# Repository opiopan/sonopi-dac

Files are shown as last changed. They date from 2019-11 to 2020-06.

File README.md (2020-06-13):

Sonopi DAC
===


<p align="center">
board image
</p>

Sonopi DAC is a hat card for Raspberry Pi to add a audio line output capability.
This hat board is designed to adapt to both of formfactor, Raspbery pi model B+ and Raspberry pi Zero.<br>
[TI PCM5122](http://www.ti.com/product/PCM5122?keyMatch=PCM5122&tisearch=Search-EN-everything&usecase=part-number) is isntalled as DAC module, and Sonopi DAC design is compatible with [Hifiberry DAC+ Pro](https://www.hifiberry.com/shop/boards/hifiberry-dac-pro/) from Raspberry Pi point of view. It means that no special driver is necessary to use Sonopi DAC.

This hardware design is published under open source lincence. You can use and modify this design freely. There is also no limitation in commercial use.

## Project Status
Circuit schema design was done. Now I'm working on board art work.<br>
And I'm also considering which production is more feasible for some parts.

## How to setup
Due to enable drivers for Sonopi DAC in Linux ALSA system, add a following line in ```/boot/config.txt```. Then rebooot a Raspberry Pi.

```
dtoverlay=hifiberry-dacplus
```

## PCB Design
<p align="center">
PCB schema
</p>

<p align="center">
board image
</p>

<p align="center">
board image
</p>

<p align="center">
board image
</p>

## BOM List
Components               | Value / Product Number      | Remarks
-------------------------|-----------------------------|------------------------------
U1                       | PCM5122                     |
U2                       | MCP1703AT-3302E/CB          | 3.3V LDO
X1                       | 22.5792MHz Oscillator (3225)|
X2                       | 24.576MHz Oscillator (3225) |
R1, R2                   | 470Ω (1608)                 |
C1, C2                   | 1uF (1608)                  |
C3, C5, C7, C11          | 10uF/16V (3216)             |
C4, C6, C8, C12, C13, C14| 0.1uF/100V (1608)           |
C9, C10                  | 2.2uF/25V (2012)            |
C15, C16                 | 2.2nF/50V (1608)            |
J1                       | HLR-3201VXB-004HG           | RCA Jack (White)
J2                       | HLR-3201VXB-003HG           | RCA Jack (Red)

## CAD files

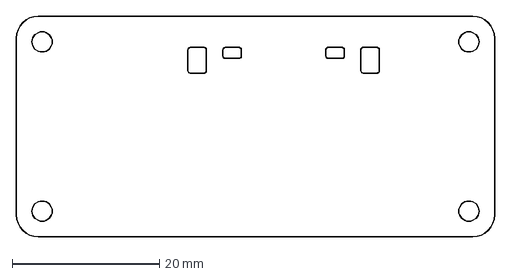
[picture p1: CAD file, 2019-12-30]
imagesrc/3dcg/outline.dxf
65.0 x 30.0 mm

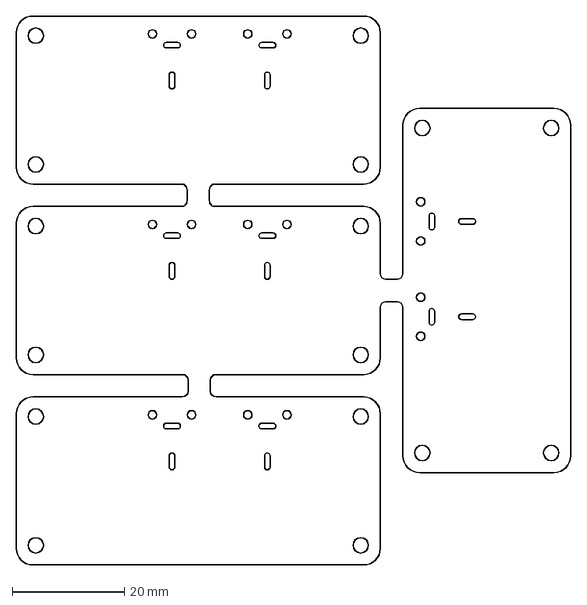
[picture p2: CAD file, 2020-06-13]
panelize/outline.dxf
99.0 x 98.0 mm

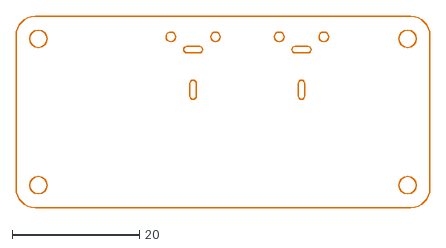
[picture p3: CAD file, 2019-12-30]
pcb/type2/sonopi-dac-type2.dxf
65.0 x 30.0

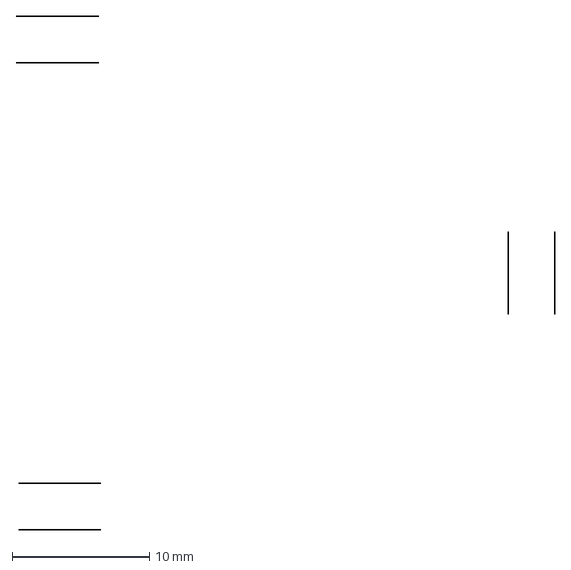
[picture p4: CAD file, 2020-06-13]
panelize/mousebites.dxf
39.2 x 37.4 mm

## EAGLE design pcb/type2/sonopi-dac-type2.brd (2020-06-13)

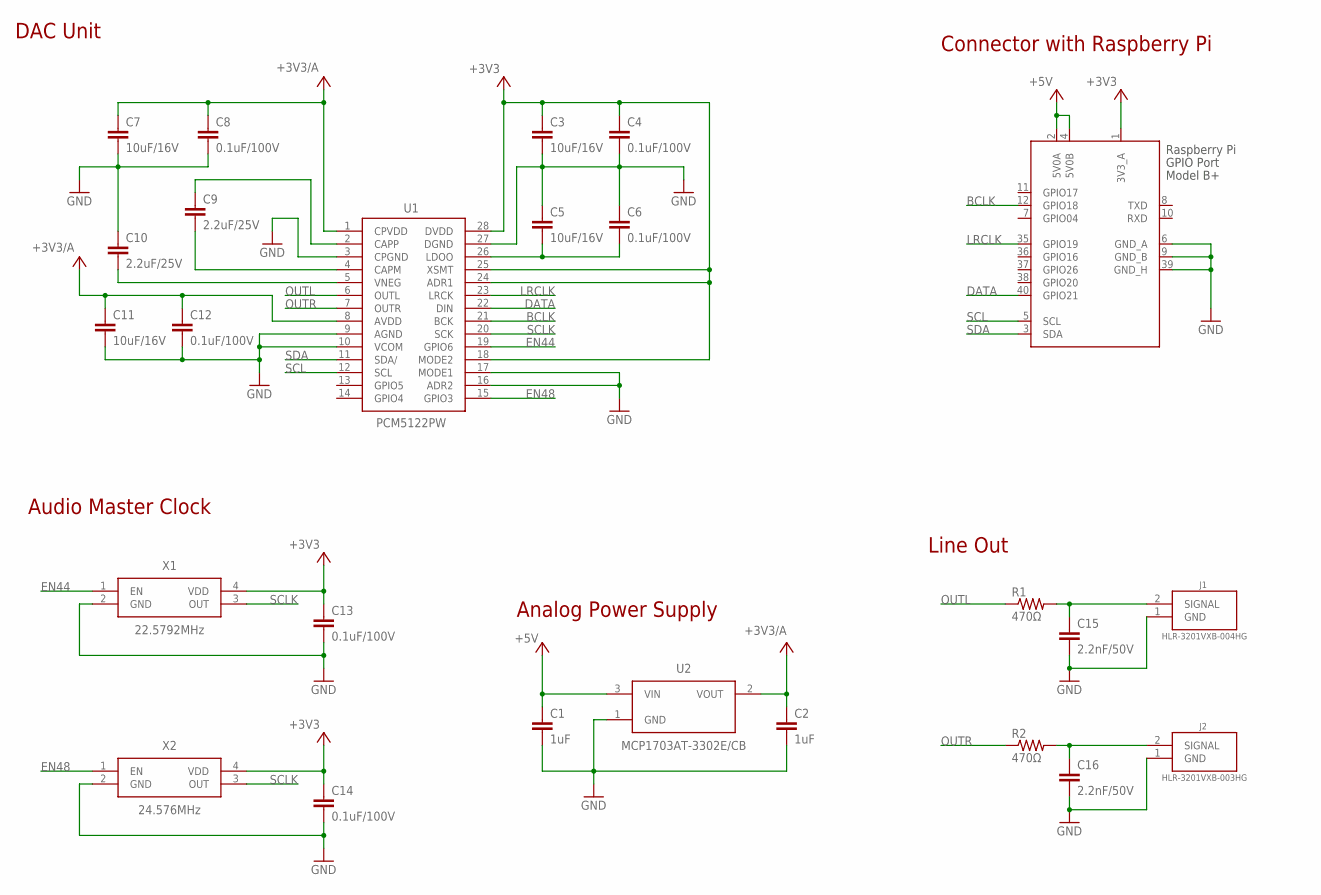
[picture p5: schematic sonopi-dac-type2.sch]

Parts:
C1, C2: 1uF; C0603
C3, C5, C7, C11: 10uF/16V; C3216
C4, C6, C8, C12, C13, C14: 0.1uF/100V; C0603
C9, C10: 2.2uF/25V; C0805
C15, C16: 2.2nF/50V; C0603
J1: HLR-3201VXB-004HG; HLR-3201VXB
J2: HLR-3201VXB-003HG; HLR-3201VXB
J3: RASPI_BOARD_B+#_ZERO; RASPI_BOARD_B+HAT_ZERO
R1, R2: 470Ω; R0603
U1: PCM5122PW; SOP65P640X120-28N
U2: MCP1703AT-3302E/CB; SOT23
X1: 22.5792MHz; 3225-SMD-HS
X2: 24.576MHz; 3225-SMD-HS

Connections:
+3V3: C3.1, C4.1, C13.1, C14.1, J3.1 (3V3_A), U1.18 (MODE2), U1.24 (ADR1), U1.25 (XSMT), U1.28 (DVDD), X1.4 (VDD), X2.4 (VDD)
+3V3/A: C2.1, C7.1, C8.1, C11.1, C12.1, U1.1 (CPVDD), U1.8 (AVDD), U2.2 (VOUT)
+5V: C1.1, J3.2 (5V0A), J3.4 (5V0B), U2.3 (VIN)
BCLK: J3.12 (GPIO18), U1.21 (BCK)
CAPM: C9.2, U1.4 (CAPM)
CAPP: C9.1, U1.2 (CAPP)
DATA: J3.40 (GPIO21), U1.22 (DIN)
EN44: U1.19 (GPIO6), X1.1 (EN)
EN48: U1.15 (GPIO3), X2.1 (EN)
GND: C1.2, C2.2, C3.2, C4.2, C5.1, C6.1, C7.2, C8.2, C10.1, C11.2, C12.2, C13.2, C14.2, C15.2, C16.2, J1.1 (GND), J2.1 (GND), J3.6 (GND_A), J3.9 (GND_B), J3.39 (GND_H), U1.3 (CPGND), U1.9 (AGND), U1.10 (VCOM), U1.16 (ADR2), U1.17 (MODE1), U1.27 (DGND), U2.1 (GND), X1.2 (GND), X2.2 (GND)
LCH: C15.1, J1.2 (SIGNAL), R1.2
LDOO: C5.2, C6.2, U1.26 (LDOO)
LRCLK: J3.35 (GPIO19), U1.23 (LRCK)
OUTL: R1.1, U1.6 (OUTL)
OUTR: R2.1, U1.7 (OUTR)
RCH: C16.1, J2.2 (SIGNAL), R2.2
SCL: J3.5 (SCL), U1.12 (SCL)
SCLK: U1.20 (SCK), X1.3 (OUT), X2.3 (OUT)
SDA: J3.3 (SDA), U1.11 (SDA/)
VNEG: C10.2, U1.5 (VNEG)

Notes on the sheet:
Analog Power Supply
Connector with Raspberry Pi
DAC Unit
Audio Master Clock
Line Out

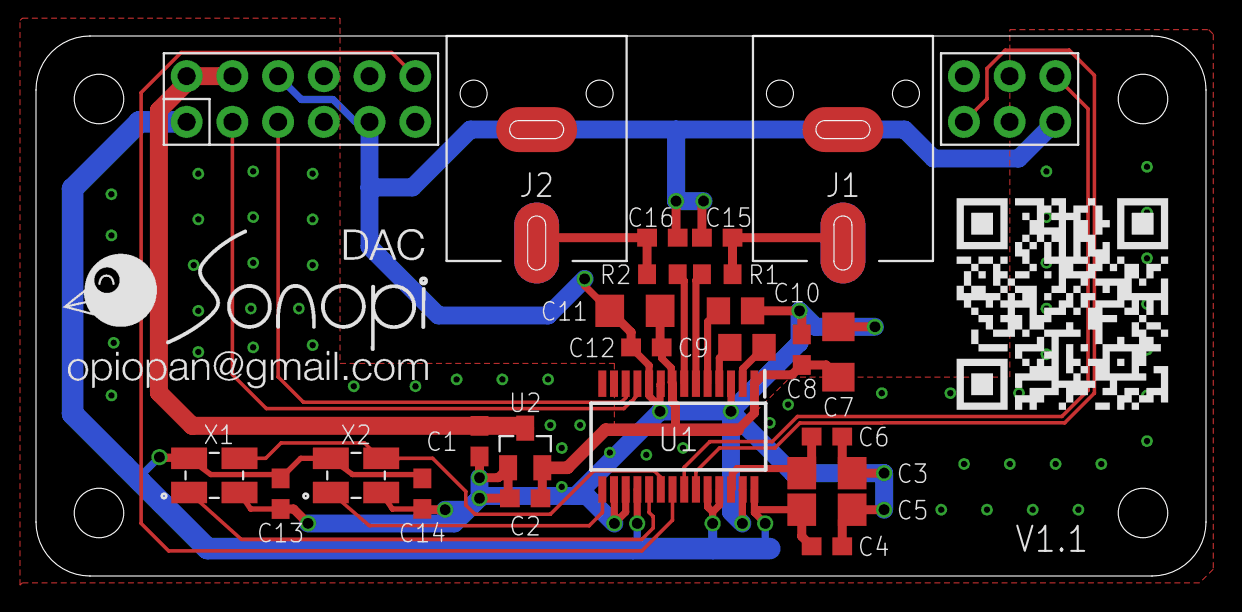
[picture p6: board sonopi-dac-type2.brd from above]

Board: 2 copper layers, 65.0 x 30.0 mm, 27 parts (0 on the bottom side), 20 nets.

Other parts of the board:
U$1: SONOPI-DAC-LOGO
U$2: SONOPI-DAC-QRCODE

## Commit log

2019-11-17 initial commit, PCB schema design done
    [sonopi-dac.sch]
2019-11-17 fix a minor bug in schema
    [sonopi-dac.sch]
2019-11-18 fix a bug that a part of coupling capaciter does not be utilized
    [sonopi-dac.sch]
2019-11-18 initial artwork done
    [sonopi-dac.brd, sonopi-dac.sch]
2019-11-21 add artwork design
    [sonopi-dac.brd, sonopi-dac.sch]
2019-11-24 fix minor probrems, and add scripts to generate decal image for 3D rendering
    [sonopi-dac.brd, sonopi-dac.sch]
2019-11-30 add another desing that Linkman RCA jack is installed
    [sonopi-dac-type2.brd, sonopi-dac-type2.sch, sonopi-dac.brd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]
2019-12-01 add BOM list
2019-12-30 add panelizing script
    [sonopi-dac-type2.brd, sonopi-dac-type2.sch]
2019-12-30 add some files for panelizing
    [mousebites.dxf, outline.dxf, sonopi-dac-type2.dxf]
2020-06-13 change footprint of 3225 oscillator
    [mousebites.dxf, outline.dxf, sonopi-dac-type2.brd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]
